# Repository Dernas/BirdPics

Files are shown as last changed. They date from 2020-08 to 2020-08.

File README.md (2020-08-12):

# BirdPics

### HARDWARE USED ###  
The hardware is a Rasberry Pi 3b+ ($35, https://www.raspberrypi.org/products/raspberry-pi-3-model-b-plus), Pi Camera V2 ($30, https://www.raspberrypi.org/products/camera-module-v2/),
32GB Samsung SD card ($7.50), Adafruit PIR sensor ($10, https://www.adafruit.com/product/189), and Adafruit Pi battery pack ($40, https://www.adafruit.com/product/1566)

Min cost = $72.5 (no battery/sensor, shipping/handling not included. Use the "timer" branch if there's no sensor).

No-battery cost = $82.5 (use either branch, works anywhere with power)

Cost with battery/sensor = $122.5 (works anywhere, needs charging about once a day - I recommend charging overnight)

### SOFTWARE USED ###
Raspberry Pi OS & this repo

### SETUP ###

## Hardware ##

1. Camera: Connect the Pi to the camera as described in camera instructions. 

2. Sensor: Solder pin headers to the connectors, then connect the red wire to pin 4, yellow to pin 29, and black to pin 20. (see https://www.raspberrypi.org/documentation/usage/gpio/ for pin numbers)

3. Battery: After charging the battery with any USB-compatible power block, plug the small end of the cable into the Pi and the large end into the battery. Make sure to recharge the battery when it runs low!

## Software ##

1. OS: Install the OS to the SD card (guide at https://www.raspberrypi.org/downloads/). Once installed, run the Pi and connect the Pi to your Wifi (you can connect it to your monitor over HDMI, then use a USB keyboard/mouse to control it)

2. Get the files: Add this software to the PI (I suggest making a folder in /home/pi, then cloning the repo into that folder. 
Example: Open a terminal with Ctrl+Alt+T. Enter "mkdir birds" to make a folder, "cd birds" to move into the folder, "sudo apt-get install git" to get git running, then "git clone https://github.com/Dernas/BirdPics.git"
to get this code. If you don't want to do all that, just download BirdSpotter.py, date.txt, and count.text to the Pi.)

3. Configure Drive: First, make a Google project to link to your Drive. See https://developers.google.com/drive/api/v3/quickstart/python?authuser=1
for instructions. Next, make a Drive folder to store the pics. Once you make the folder, replace the line
            "parents": ["15Xn3O4BaGPRjun25PWNGyAZIX6p8NLFz"]
			with
			"parents": ["YOUR_FOLDER_ID"] in BirdSpotter and ManualPicTaker.
To get the ID, go into the folder and look at the URL (something like https://drive.google.com/drive/u/0/folders/15Xn3O4BaGPRjun25PWNGyAZIX6p8NLFz")
You want the part after "folders/".

4. Version choice: If you want the IR version, skip to the next step. If you want the timer version, use "git checkout origin/timer"

5. Run on startup: There are many ways to run this process at startup. I used systemd (suggested by https://www.dexterindustries.com/howto/run-a-program-on-your-raspberry-pi-at-startup/).
Example: In a terminal, enter "sudo nano /lib/systemd/system/birds.service" to make a service file, then enter:
[Unit]
Description=Automatic Bird Pictures
After=network.target

[Service]
ExecStart=/usr/bin/python3 -u BirdSpotter.py
WorkingDirectory=/home/pi/birds
StandardOutput=inherit
StandardError=inherit
Restart=always

[Install]
WantedBy=multi-user.target

After that, set permissions on your service ("sudo chmod 644 /lib/systemd/system/birds.service"), then tell the Pi to run it on startup ("sudo systemctl daemon-reload", "sudo systemctl enable sample.service"). After a reboot, the program should run every time you start the Pi!

6. (OPTIONAL) Easy manual pictures: To do this, you'll need a way to connect to your pi. I used SSH (https://www.raspberrypi.org/documentation/remote-access/ssh/). Once you're connected, you can use "sudo python3 /home/pi/birds/ManualPicTaker.py", or you can make it easy - use "sudo nano .bashrc", then add
"PATH=$PATH:/home/pi/.local/bin
alias bird=sudo python3 /home/pi/birds/ManualPicTaker.py"
The first command tells the Pi where to look for python, and the second one (reboot to make this work) lets you take a picture by typing "bird" as soon as you connect. Good luck!

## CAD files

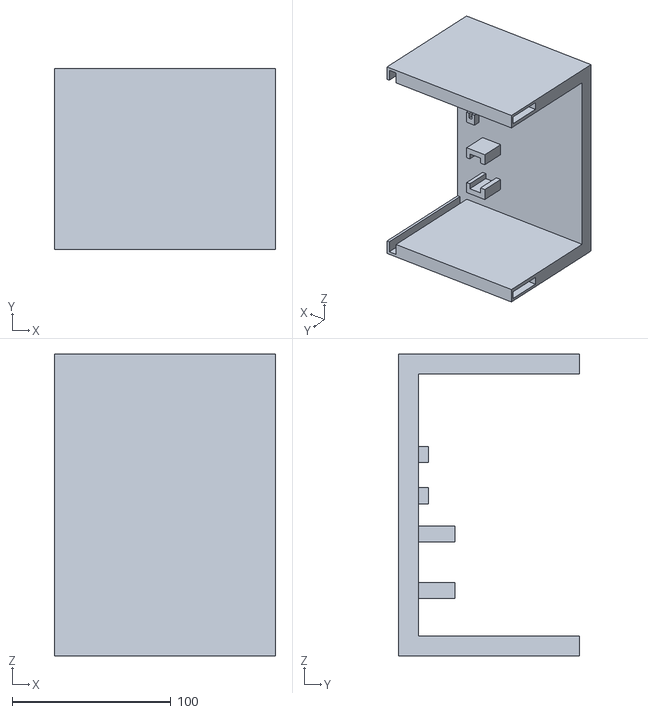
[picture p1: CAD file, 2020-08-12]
CaseFiles/BirdBasePlate.STL
139.7 x 114.3 x 190.5

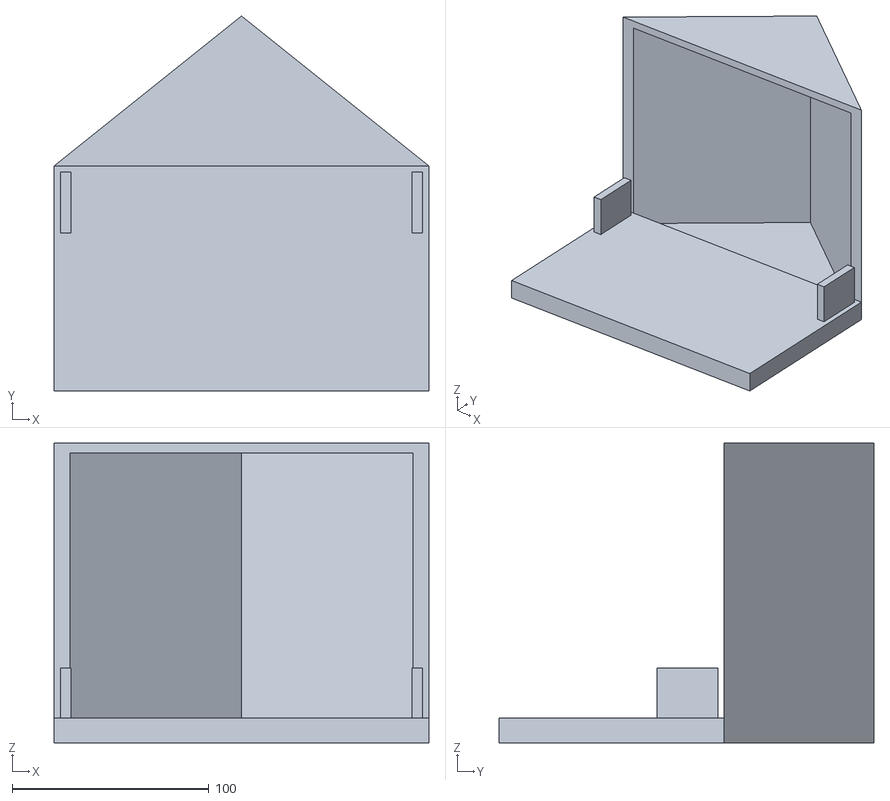
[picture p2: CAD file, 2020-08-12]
CaseFiles/BirdRoof.STL
190.5 x 190.5 x 152.4

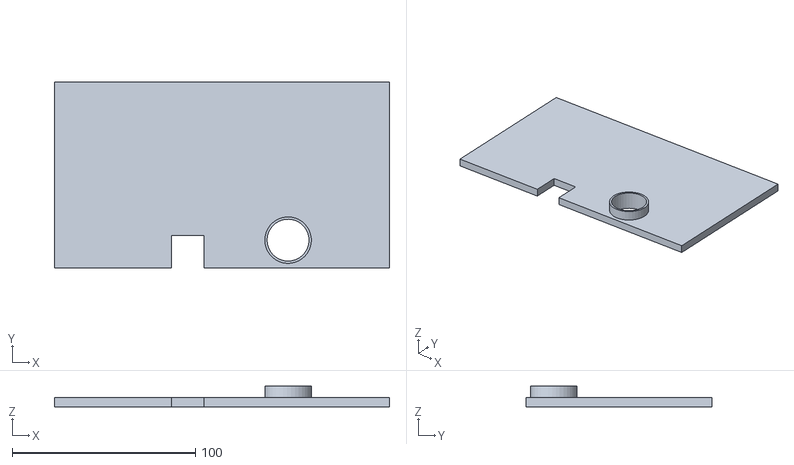
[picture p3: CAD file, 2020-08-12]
CaseFiles/BirdFacePlate.STL
182.9 x 101.6 x 11.4

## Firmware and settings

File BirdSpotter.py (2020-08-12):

import pickle
import os
import os.path
import time
import datetime
import RPi.GPIO as GPIO
from picamera import PiCamera
from googleapiclient.http import MediaFileUpload
from googleapiclient.discovery import build
from google_auth_oauthlib.flow import InstalledAppFlow
from google.auth.transport.requests import Request

pic_count = 0
current_day = datetime.date.today()
# global so it can accessed by main, takepic and update_count.
# take_pic is used as a callback, so it can't return a count increment, and this lets us use it in both functions


def main():
    # Check if IR sensor has picked up any birds.
    # 1 min delay before taking any pics, allow Pi to boot
    time.sleep(60)
    pir_input = 29
    start_pir(pir_input)
    start_time = datetime.time(5, 0, 0)
    end_time = datetime.time(21, 0, 0)
    global pic_count
    check_date()
    sensor = False
    while 1:
        current_time = datetime.datetime.now().time()
        if start_time < current_time < end_time and not sensor:
            # If we're in the correct time range and not checking for birds, start looking
            GPIO.add_event_detect(pir_input, GPIO.BOTH, callback=take_pic, bouncetime=200)
            sensor = True
        elif start_time < current_time < end_time:
            pass
        elif sensor:
            # Assumed no birds between 21:00 and 5:00
            GPIO.remove_event_detect(pir_input)
            sensor = False
        time.sleep(60)


def check_date():
    global pic_count
    # Check to see if it's a new day
    with open("Date.txt") as f:
        olddate = f.readline()
    date = datetime.date.today().strftime("%d-%b-%Y")
    if olddate == date:
        # If the day hasn't changed, we had a reboot or auto-check and should pick up the count where we left off
        with open("Count.txt") as g:
            pic_count = int(g.readline())
    else:
        # If it has, we set pic_count to 1 and update the date + saved count
        with open("Date.txt", "w") as f:
            f.write(date)
        with open("Count.txt", "r+") as g:
            g.write("1")
        pic_count = 1


def take_pic(channel):
    # Take the picture. Don't need the channel, but GPIO passes a number
    global pic_count
    camera = PiCamera()
    camera.vflip = True
    camera.hflip = True
    camera.start_preview()
    # set the dir
    ourdir = "/home/pi/Birds/BirdPics/"
    picname = ourdir + "AutoPicture " + str(pic_count) + ".jpg"
    # Save the pic, using pic_num to keep track
    time.sleep(2)
    # Camera needs 2 seconds to adjust
    camera.capture(picname)
    camera.stop_preview()
    camera.close()
    # Send it to the drive
    try:
        send_pic(picname, ourdir)
        send_offlines(ourdir)
        # If we got to this function, we have a connection again
    except:
        # This should be a more precise error, really just looking for if there's no connection. File is still saved
        # locally, and will be sent once connection is back
        # Rename the file to indicate it was saved offline
        os.rename(r"%s" % picname, r"OfflinePic " + datetime.datetime.now().strftime("%H:%M %d-%b-%Y") + ".jpg")
        pass
    update_count()


def update_count():
    global pic_count
    global current_day
    pic_count += 1
    with open("Count.txt", "w+") as f:
        f.write("%d" % pic_count)
    if datetime.date.today() != current_day:
        check_date()
        current_day = datetime.date.today()


def start_pir(pir_input):
    # Pi pinout from https://www.raspberrypi.org/documentation/usage/gpio/
    # Base code from https://www.electronicwings.com/raspberry-pi/pir-motion-sensor-interfacing-with-raspberry-pi
    GPIO.setwarnings(False)
    GPIO.setmode(GPIO.BOARD)
    GPIO.setup(pir_input, GPIO.IN)


def login(ourdir):
    # Google login code taken from https://developers.google.com/drive/api/v3/quickstart/python?authuser=1
    SCOPES = ['https://www.googleapis.com/auth/drive']  # Needs to create folders/files, see if folder exists
    creds = None
    # The file token.pickle stores the user's access and refresh tokens, and is
    # created automatically when the authorization flow completes for the first
    # time
    if os.path.exists(ourdir + 'token.pickle'):
        with open(ourdir + 'token.pickle', 'rb') as token:
            creds = pickle.load(token)
    # If there are no (valid) credentials available, let the user log in.
    if not creds or not creds.valid:
        if creds and creds.expired and creds.refresh_token:
            creds.refresh(Request())
        else:
            flow = InstalledAppFlow.from_client_secrets_file(
               ourdir + 'credentials.json', SCOPES)
            creds = flow.run_local_server(port=0)
        # Save the credentials for the next run
        with open(ourdir + 'token.pickle', 'wb') as token:
            pickle.dump(creds, token)
    service = build('drive', 'v3', credentials=creds)
    return service


def send_offlines(ourdir):
    # Send any pictures that were taken while offline to the drive
    service = login(ourdir)
    # check files in dir:
    for file in os.listdir(ourdir):
        if "Offline" in file:
            picturename = file.split(".")[0]
            # Get a nice name for the picture
            pic = MediaFileUpload(ourdir + "/" + file, mimetype="image/jpeg")
            pic_meta = {"name": picturename,
                        "parents": ["15Xn3O4BaGPRjun25PWNGyAZIX6p8NLFz"]}
            # Dump it into the main folder, let user use timestamps to sort
            service.files().create(body=pic_meta,
                                   media_body=pic,
                                   fields="id").execute()
            os.remove(file)


def send_pic(picname, ourdir):
    # Get the date for folder check
    day = datetime.date.today()
    foldername = "AutoBirdPics " + day.strftime("%d-%b-%Y")
    service = login(ourdir)
    # Check for a folder matching current date
    results = service.files().list(
        q="name='{0}'".format(foldername),
        spaces="drive",
        fields="nextPageToken, files(id, name)").execute()
    items = results.get('files', [])
    if not items:
        # If it doesn't exist, create it
        # Format - AutoBirdPics dd-mon-yyyy
        folder_metadata = {
            "name": foldername,
            "mimeType": "application/vnd.google-apps.folder",
            "parents": ["15Xn3O4BaGPRjun25PWNGyAZIX6p8NLFz"]
            # The ID of the BirdPics folder. Must be in a list to work as a parent
        }
        folder = service.files().create(body=folder_metadata,
                                        fields="id").execute()
        folderid = folder.get("id")
    else:
        # If it exists, get the ID
        folderid = items[0].get("id")

    filename = picname.split("/")[-1]
    picturename = filename.split(".")[0]
    # Get a nice name for the picture

    # Add pic to today's folder
    pic = MediaFileUpload(picname, mimetype="image/jpeg")
    pic_meta = {"name": picturename,
                "parents": ["{0}".format(folderid)]}
    # Google likes IDs better than names, so use the ID of the folder we made
    service.files().create(body=pic_meta,
                           media_body=pic,
                           fields="id").execute()


if __name__ == "__main__":
    main()

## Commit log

2020-07-15 Now on fixed 10 min timer
    [BirdSpotter.py]
2020-07-15 fix for not looping
    [BirdSpotter.py]
2020-07-15 Fix upside-down camera
2020-07-15 Removed print statement
2020-07-16 Reset counter when run overnight
    [BirdSpotter.py]
2020-07-17 Added checks for new day, count persistance on reboot
    [BirdSpotter.py]
2020-07-19 Trying IR sensor
2020-07-19 testing print
2020-08-04 Redid GPIO input to improve sensor
2020-08-05 fix for GPIO not working
    [BirdSpotter.py]
2020-08-12 added STL files
    [BirdBasePlate.STL, BirdFacePlate.STL, BirdRoof.STL]
